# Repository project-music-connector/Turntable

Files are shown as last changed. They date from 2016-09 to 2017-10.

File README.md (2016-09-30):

# Turntable

The Turntable (inspired by Avoka's [Dyskograf](https://www.avoka.fr/portfolio/dyskograf/)) is an Arduino-powered turntable for which you can draw your own "vinyls". These drawings on circular discs, detected by infrared sensors, are transformed into looping music.
A Processing code reads the sensor data and interprets it, playing or generating sounds using the Processing 3 Sound library.

<br />This work is licensed under a <a rel="license" href="http://creativecommons.org/licenses/by-sa/4.0/">Creative Commons Attribution-ShareAlike 4.0 International License</a>.

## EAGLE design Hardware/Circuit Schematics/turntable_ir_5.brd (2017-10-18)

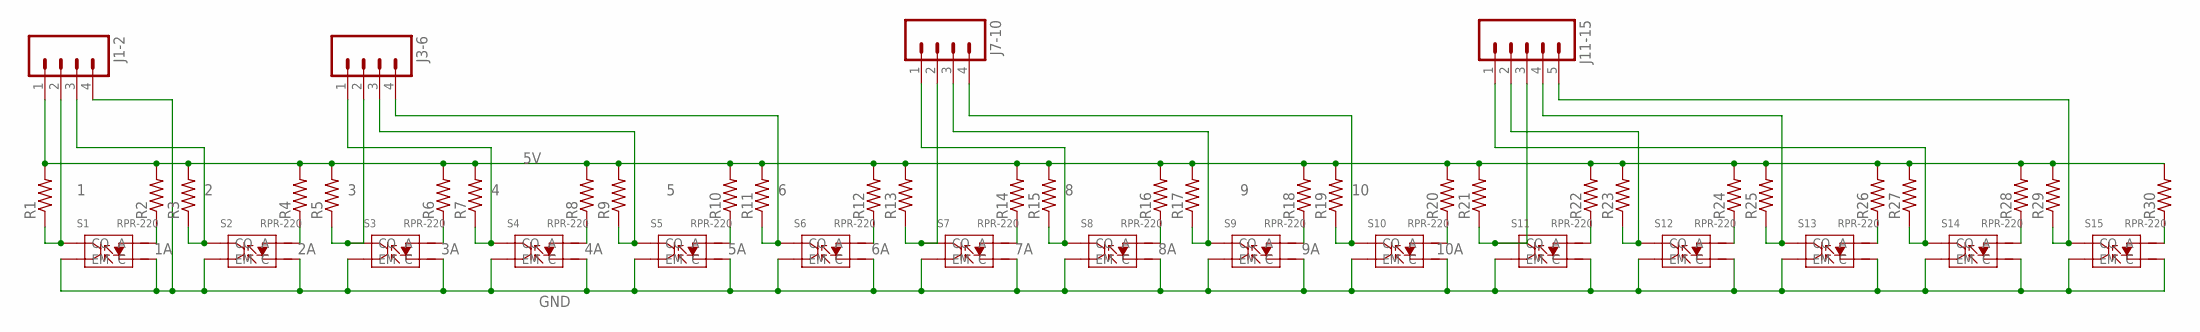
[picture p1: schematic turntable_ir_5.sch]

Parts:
J1-2, J3-6, J7-10: M04NO_SILK_ALL_ROUND; 1X04_NO_SILK_ALL_ROUND
J11-15: M05NO_SILK; 1X05_NO_SILK
R1, R2, R3, R4, R5, R6, R7, R8, R9, R10, R11, R12, R13, R14, R15, R16, R17, R18, R19, R20, R21, R22, R23, R24, R25, R26, R27, R28, R29, R30: RESISTOR1206; 1206
S1, S2, S3, S4, S5, S6, S7, S8, S9, S10, S11, S12, S13, S14, S15: RPR-220; RPR-220-6.4X4.9X6.5

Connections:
1: J1-2.2, R1.1, S1.P$4 (CO)
1A: R2.1, S1.P$1 (A)
2: J1-2.3, R3.1, S2.P$4 (CO)
2A: R4.1, S2.P$1 (A)
3: J3-6.2, R5.1, S3.P$4 (CO)
3A: R6.1, S3.P$1 (A)
4: J3-6.1, R7.1, S4.P$4 (CO)
4A: R8.1, S4.P$1 (A)
5: J3-6.3, R9.1, S5.P$4 (CO)
5A: R10.1, S5.P$1 (A)
5V: J1-2.1, R1.2, R2.2, R3.2, R4.2, R5.2, R6.2, R7.2, R8.2, R9.2, R10.2, R11.2, R12.2, R13.2, R14.2, R15.2, R16.2, R17.2, R18.2, R19.2, R20.2, R21.2, R22.2, R23.2, R24.2, R25.2, R26.2, R27.2, R28.2, R29.2, R30.2
6: J3-6.4, R11.1, S6.P$4 (CO)
6A: R12.1, S6.P$1 (A)
7: J7-10.2, R13.1, S7.P$4 (CO)
7A: R14.1, S7.P$1 (A)
8: J7-10.1, R15.1, S8.P$4 (CO)
8A: R16.1, S8.P$1 (A)
9: J7-10.3, R17.1, S9.P$4 (CO)
9A: R18.1, S9.P$1 (A)
10: J7-10.4, R19.1, S10.P$4 (CO)
10A: R20.1, S10.P$1 (A)
11: J11-15.3, R21.1, S11.P$4 (CO)
11A: R22.1, S11.P$1 (A)
12: J11-15.2, R23.1, S12.P$4 (CO)
12A: R24.1, S12.P$1 (A)
13: J11-15.4, R25.1, S13.P$4 (CO)
13A: R26.1, S13.P$1 (A)
14: J11-15.1, R27.1, S14.P$4 (CO)
14A: R28.1, S14.P$1 (A)
15: J11-15.5, R29.1, S15.P$4 (CO)
15A: R30.1, S15.P$1 (A)
GND: J1-2.4, S1.P$2 (C), S1.P$3 (EM), S2.P$2 (C), S2.P$3 (EM), S3.P$2 (C), S3.P$3 (EM), S4.P$2 (C), S4.P$3 (EM), S5.P$2 (C), S5.P$3 (EM), S6.P$2 (C), S6.P$3 (EM), S7.P$2 (C), S7.P$3 (EM), S8.P$2 (C), S8.P$3 (EM), S9.P$2 (C), S9.P$3 (EM), S10.P$2 (C), S10.P$3 (EM), S11.P$2 (C), S11.P$3 (EM), S12.P$2 (C), S12.P$3 (EM), S13.P$2 (C), S13.P$3 (EM), S14.P$2 (C), S14.P$3 (EM), S15.P$2 (C), S15.P$3 (EM)

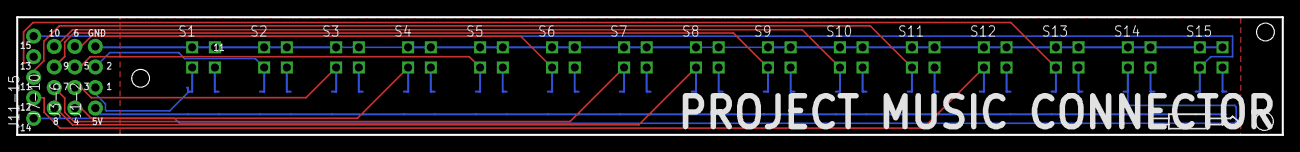
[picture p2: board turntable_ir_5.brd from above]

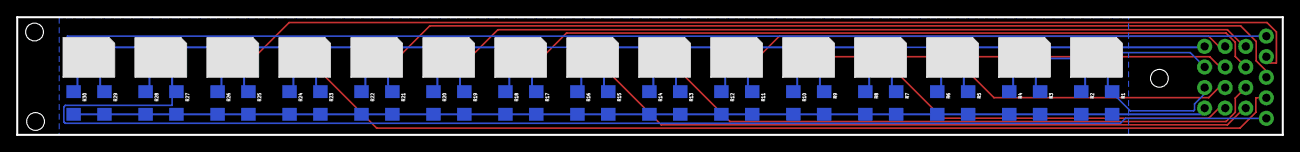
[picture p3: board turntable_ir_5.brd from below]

Board: 2 copper layers, 156.3 x 14.5 mm, 49 parts (30 on the bottom side), 32 nets.

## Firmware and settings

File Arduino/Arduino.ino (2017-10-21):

//by Alice Barbe and Beatriz Fusaro

#include <math.h>
  
//Infrared Sensor Pins
const int irPin0  = A0;
const int irPin1  = A1;
const int irPin2  = A2;
const int irPin3  = A3;
const int irPin4  = A4;
const int irPin6  = A6;
const int irPin5  = A5;
const int irPin7  = A7;
const int irPin8  = A8;
const int irPin9  = A9;
const int irPin10 = A10;
const int irPin11 = A11;
const int irPin12 = A12;
const int irPin13 = A13;
const int irPin14 = A14;

//Switch pins
const int switch1  = 28;
const int switch2  = 29;
const int switch3  = 30;
const int switch4  = 31;
const int switch5  = 32;
const int switch6  = 33;
const int switch7  = 34;
const int switch8  = 35;
const int switch9  = 36;
const int switch10 = 37;
const int switch11 = 38;
const int switch12 = 39;

//Potentiometer pin for controlling motor speed
const int potPin = A15;

int pv0[5] = {0, 0, 0, 0, 0};
int pv1[5] = {0, 0, 0, 0, 0};
int pv2[5] = {0, 0, 0, 0, 0};
int pv3[5] = {0, 0, 0, 0, 0};
int pv4[5] = {0, 0, 0, 0, 0};
int pv5[5] = {0, 0, 0, 0, 0};
int pv6[5] = {0, 0, 0, 0, 0};
int pv7[5] = {0, 0, 0, 0, 0};
int pv8[5] = {0, 0, 0, 0, 0};
int pv9[5] = {0, 0, 0, 0, 0};
int pv10[5] = {0, 0, 0, 0, 0};
int pv11[5] = {0, 0, 0, 0, 0};
int pv12[5] = {0, 0, 0, 0, 0};
int pv13[5] = {0, 0, 0, 0, 0};
int pv14[5] = {0, 0, 0, 0, 0};
int value = 0;

int RunningAverage(int newer, int value, int pv[5]) {
  pv[value] = newer;
  int sum = 0;
  for (int i = 0; i < 5; i++) {
    sum += pv[i];
  }
  return sum/5;
}

void setup() {
  // initialize serial communications at 9600 bps:
  Serial.begin(9600);
  
  //make switch pins inputs
  pinMode(switch1, INPUT_PULLUP);
  pinMode(switch2, INPUT_PULLUP);
  pinMode(switch3, INPUT_PULLUP);
  pinMode(switch4, INPUT_PULLUP);
  pinMode(switch5, INPUT_PULLUP);
  pinMode(switch6, INPUT_PULLUP);  
  pinMode(switch7, INPUT_PULLUP);
  pinMode(switch8, INPUT_PULLUP);
  pinMode(switch9, INPUT_PULLUP);
  pinMode(switch10, INPUT_PULLUP);
  pinMode(switch11, INPUT_PULLUP);
  pinMode(switch12, INPUT_PULLUP);
}

void loop() {
  // read the analog in value of the IR sensors:
  int analogIRPin0  = analogRead(irPin0);
  int analogIRPin1  = analogRead(irPin1);
  int analogIRPin2  = analogRead(irPin2);
  int analogIRPin3  = analogRead(irPin3);
  int analogIRPin4  = analogRead(irPin4);
  int analogIRPin5  = analogRead(irPin5);
  int analogIRPin6  = analogRead(irPin6);
  int analogIRPin7  = analogRead(irPin7);
  int analogIRPin8  = analogRead(irPin8);
  int analogIRPin9  = analogRead(irPin9);
  int analogIRPin10 = analogRead(irPin10);
  int analogIRPin11 = analogRead(irPin11);
  int analogIRPin12 = analogRead(irPin12);
  int analogIRPin13 = analogRead(irPin13);
  int analogIRPin14 = analogRead(irPin14);
  analogIRPin0  = RunningAverage(analogIRPin0, value, pv0);
  analogIRPin1  = RunningAverage(analogIRPin1, value, pv1);
  analogIRPin2  = RunningAverage(analogIRPin2, value, pv2);
  analogIRPin3  = RunningAverage(analogIRPin3, value, pv3);
  analogIRPin4  = RunningAverage(analogIRPin4, value, pv4);
  analogIRPin5  = RunningAverage(analogIRPin5, value, pv5);
  analogIRPin6  = RunningAverage(analogIRPin6, value, pv6);
  analogIRPin7  = RunningAverage(analogIRPin7, value, pv7);
  analogIRPin8  = RunningAverage(analogIRPin8, value, pv8);
  analogIRPin9  = RunningAverage(analogIRPin9, value, pv9);
  analogIRPin10 = RunningAverage(analogIRPin10, value, pv10);
  analogIRPin11 = RunningAverage(analogIRPin11, value, pv11);
  analogIRPin12 = RunningAverage(analogIRPin12, value, pv12);
  analogIRPin13 = RunningAverage(analogIRPin13, value, pv13);
  analogIRPin14 = RunningAverage(analogIRPin14, value, pv14);
  value += 1;
  if (value == 5){
    value = 0;
  }

  // read the input pin:
  int switchPin1  = digitalRead(switch1);
  int switchPin2  = digitalRead(switch2);
  int switchPin3  = digitalRead(switch3);
  int switchPin4  = digitalRead(switch4);
  int switchPin5  = digitalRead(switch5);
  int switchPin6  = digitalRead(switch6);
  int switchPin7  = digitalRead(switch7);
  int switchPin8  = digitalRead(switch8);
  int switchPin9  = digitalRead(switch9);
  int switchPin10 = digitalRead(switch10);
  int switchPin11 = digitalRead(switch11);
  int switchPin12 = digitalRead(switch12);
  
  /*The Serial.print() doesn't have a space
  the ',' is used to parse the values in processing
  the last value does not require the ',' 
  but make sure you have a blank Serial.println(); following it*/
  // print the results to the serial monitor:
  
  Serial.print(analogIRPin0, DEC);
  Serial.print(",");
  Serial.print(analogIRPin1, DEC);
  Serial.print(",");
  Serial.print(analogIRPin2, DEC);
  Serial.print(",");
  Serial.print(analogIRPin3, DEC);
  Serial.print(",");
  Serial.print(analogIRPin4, DEC);
  Serial.print(",");
  Serial.print(analogIRPin5, DEC);
  Serial.print(",");
  Serial.print(analogIRPin6, DEC);
  Serial.print(",");
  Serial.print(analogIRPin7, DEC);
  Serial.print(",");
  Serial.print(analogIRPin8, DEC);
  Serial.print(",");
  Serial.print(analogIRPin9, DEC);
  Serial.print(",");
  Serial.print(analogIRPin10, DEC);
  Serial.print(",");
  Serial.print(analogIRPin11, DEC);
  Serial.print(",");
  Serial.print(analogIRPin12, DEC);
  Serial.print(",");
  Serial.print(analogIRPin13, DEC);
  Serial.print(",");
  Serial.print(analogIRPin14, DEC);
  Serial.print(",");
  
  // print switch results to serial
  if (switchPin1 == LOW || switchPin7 == LOW) {
    Serial.print(1, DEC);
  } else if (switchPin2 == LOW || switchPin8 == LOW) {
    Serial.print(2, DEC);
  } else if (switchPin3 == LOW || switchPin9 == LOW) {
    Serial.print(3, DEC);
  } else if (switchPin4 == LOW || switchPin10 == LOW) {
    Serial.print(4, DEC);
  } else if (switchPin5 == LOW || switchPin11 == LOW) {
    Serial.print(5, DEC);
  } else if (switchPin6 == LOW || switchPin12 == LOW) {
    Serial.print(6, DEC);
  } else {
    Serial.print(1, DEC); //default to 1 in case the switch skips a beat
  }
  
  Serial.print(",");
  Serial.println();

  // wait 50 milliseconds before the next loop
  // for the analog-to-digital converter to settle
  // after the last reading, and to allow Processing
  // to process the information:
  delay(50);
}

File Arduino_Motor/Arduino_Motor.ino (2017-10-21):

// ConstantSpeed.pde
// -*- mode: C++ -*-
//
// Shows how to run AccelStepper in the simplest,
// fixed speed mode with no accelerations
/// \author  Mike McCauley (mikem@airspayce.com)
// Copyright (C) 2009 Mike McCauley
// $Id: ConstantSpeed.pde,v 1.1 2011/01/05 01:51:01 mikem Exp mikem $
#include <AccelStepper.h>

#define HALFSTEP  8
// Motor pin definitions

#define motorPin1 2     // IN1 on the ULN2003 driver 1
#define motorPin2 3     // IN2 on the ULN2003 driver 1
#define motorPin3 4     // IN3 on the ULN2003 driver 1
#define motorPin4 5     // IN4 on the ULN2003 driver 1

// Initialize with pin sequence IN1-IN3-IN2-IN4 for using the AccelStepper with 28BYJ-48
AccelStepper stepper(HALFSTEP, motorPin1, motorPin3, motorPin2, motorPin4);

//Potentiometer pin for controlling motor speed
const int potPin = A5;

void setup()
{  
   stepper.setMaxSpeed(1000);
   stepper.setSpeed(50);        
}
void loop()
{  

  // read potentiometer value: between 0 and 1023
  stepper.setSpeed(analogRead(potPin));
  stepper.runSpeed();
}

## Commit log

2016-08-28 Add Arduino files
    Arduino.ino outputs the data in DEC form so that Processing may read it.
    Arduino_test.ino outputs the data in a form most convenient for reading
    it with the serial monitor or plotter. This is the code we used to test
    the sensors.
2016-09-01 Added switches and changed array names
2016-09-03 Create Hardware folder for data sheets and CAD files
2016-09-03 Add switches and potentiometer
2016-09-06 Increase delay
    This seems to solve our speed issues in Processing.
    [Arduino.ino]
2016-09-07 Update and rename wSwitches.ino to Arduino.ino
2016-09-07 Added changes from Processing_test_2, fixed bug
    [Processing.pde]
2016-09-07 Revert "Delete Arduino.ino"
    This reverts commit e10e111698f22d2bb6d359d08de0e31ea692eceb.
    [Arduino.ino]
2016-09-11 Add switch to control speed of motor
2016-09-11 Replaced switch by potentiometer for motor speed
    [Arduino.ino]
2016-09-11 Added and renamed stl files
    [Arm Cover.stl, Arm Cover1.stl, Sensor Arm.stl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]
2016-09-17 Add circuit schematics
2016-09-17 Create 3D-Printed Parts folder
    [Arm Cover.stl, Arm Cover1.stl, Arm Cover2.stl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]
2016-09-17 Revert "Add circuit schematics"
    This reverts commit 2bf2f11e3ec718a38d9ed1d62c2e9a69b671a327.
2016-09-17 Reorganized folder
    [Arm Cover.stl, Arm Cover1.stl, Arm Cover2.stl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]
2016-09-26 Processing 1 (#2)
    * Add files via upload
    * Add running average to smoothen sensor signal
2016-09-27 Change switch
2016-09-30 Update switch
2016-10-16 Remove EAGLE schematic
    [turntable.sch]
2017-10-18 Changed arduino code to include new motor and pull down resistors
2017-10-18 update hardware
    [Acrilic2.DXF, Arm Cover.stl, Arm Cover1.stl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]
2017-10-20 Update code
    Arduino code: add new pins, edit motor code
    Processing code: add new pins with duplicate sounds
2017-10-21 Fix motor issues. Turntable now working.
    [Arduino.ino, Arduino_Motor.ino, Processing.pde]

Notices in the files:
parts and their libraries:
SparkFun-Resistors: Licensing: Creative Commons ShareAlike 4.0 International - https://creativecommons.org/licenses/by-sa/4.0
